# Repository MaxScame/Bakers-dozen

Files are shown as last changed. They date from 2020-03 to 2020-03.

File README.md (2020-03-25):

# Baker's dozen👻
#### [This text in russian➡️](https://github.com/MaxScame/Bakers-dozen/blob/master/README_RU.md)

40% ortholinear keyboard

---
### Layout

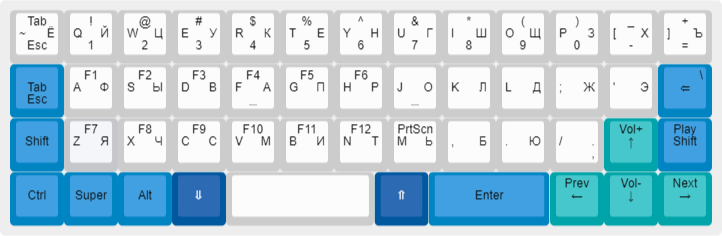
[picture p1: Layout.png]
Keeb-layout Default layout


### PCB

Front:
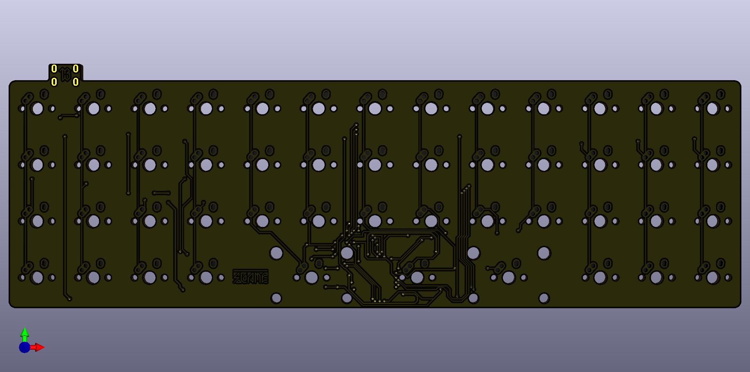
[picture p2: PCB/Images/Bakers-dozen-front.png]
PCB-Front Front side


Back:
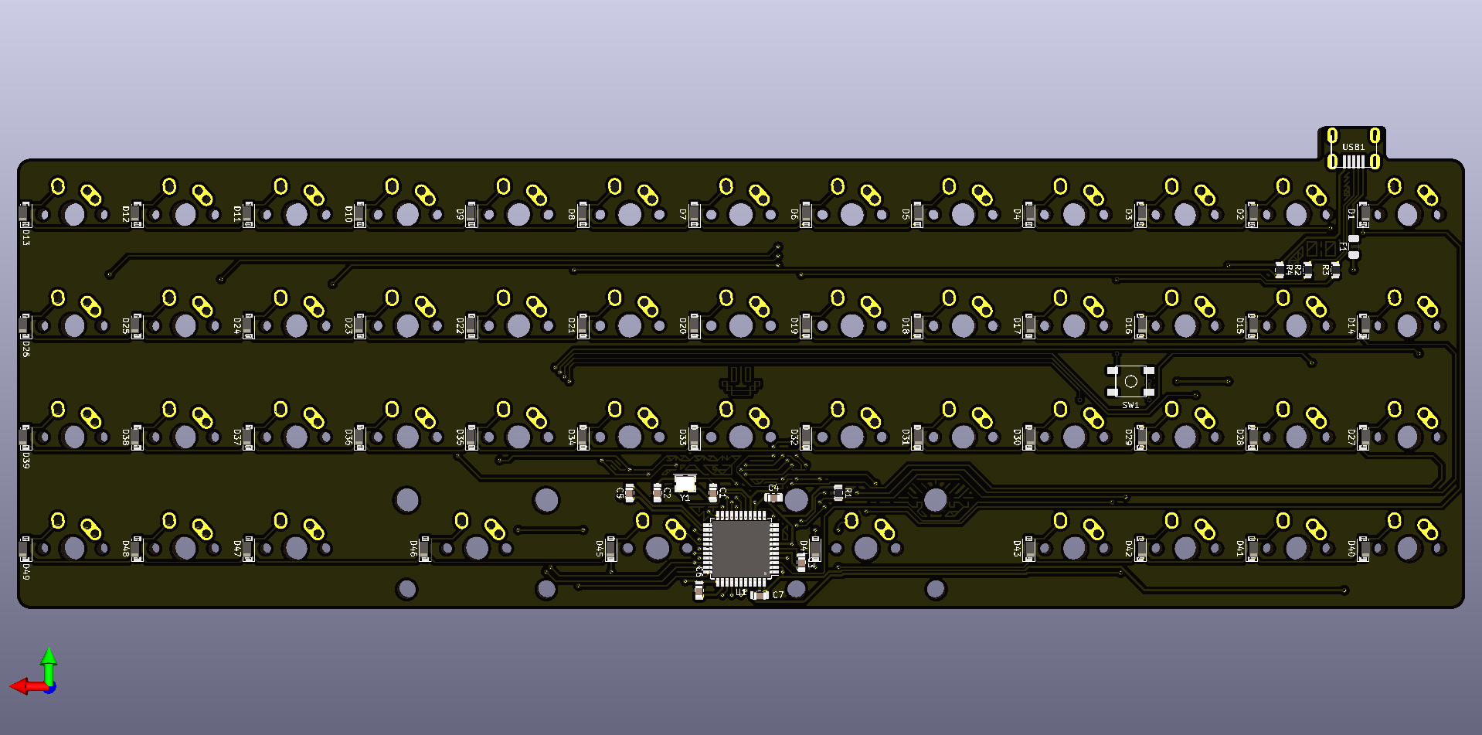
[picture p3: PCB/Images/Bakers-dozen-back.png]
PCB-Back Back side


---
### License
This project is licensed by [MIT](https://github.com/MaxScame/Bakers-dozen/blob/master/LICENSE)

### Credits
ai03-2725 for
- [MX_Alps_Hybrid](https://github.com/ai03-2725/MX_Alps_Hybrid)
- [random-keyboard-parts.pretty](https://github.com/ai03-2725/random-keyboard-parts.pretty)

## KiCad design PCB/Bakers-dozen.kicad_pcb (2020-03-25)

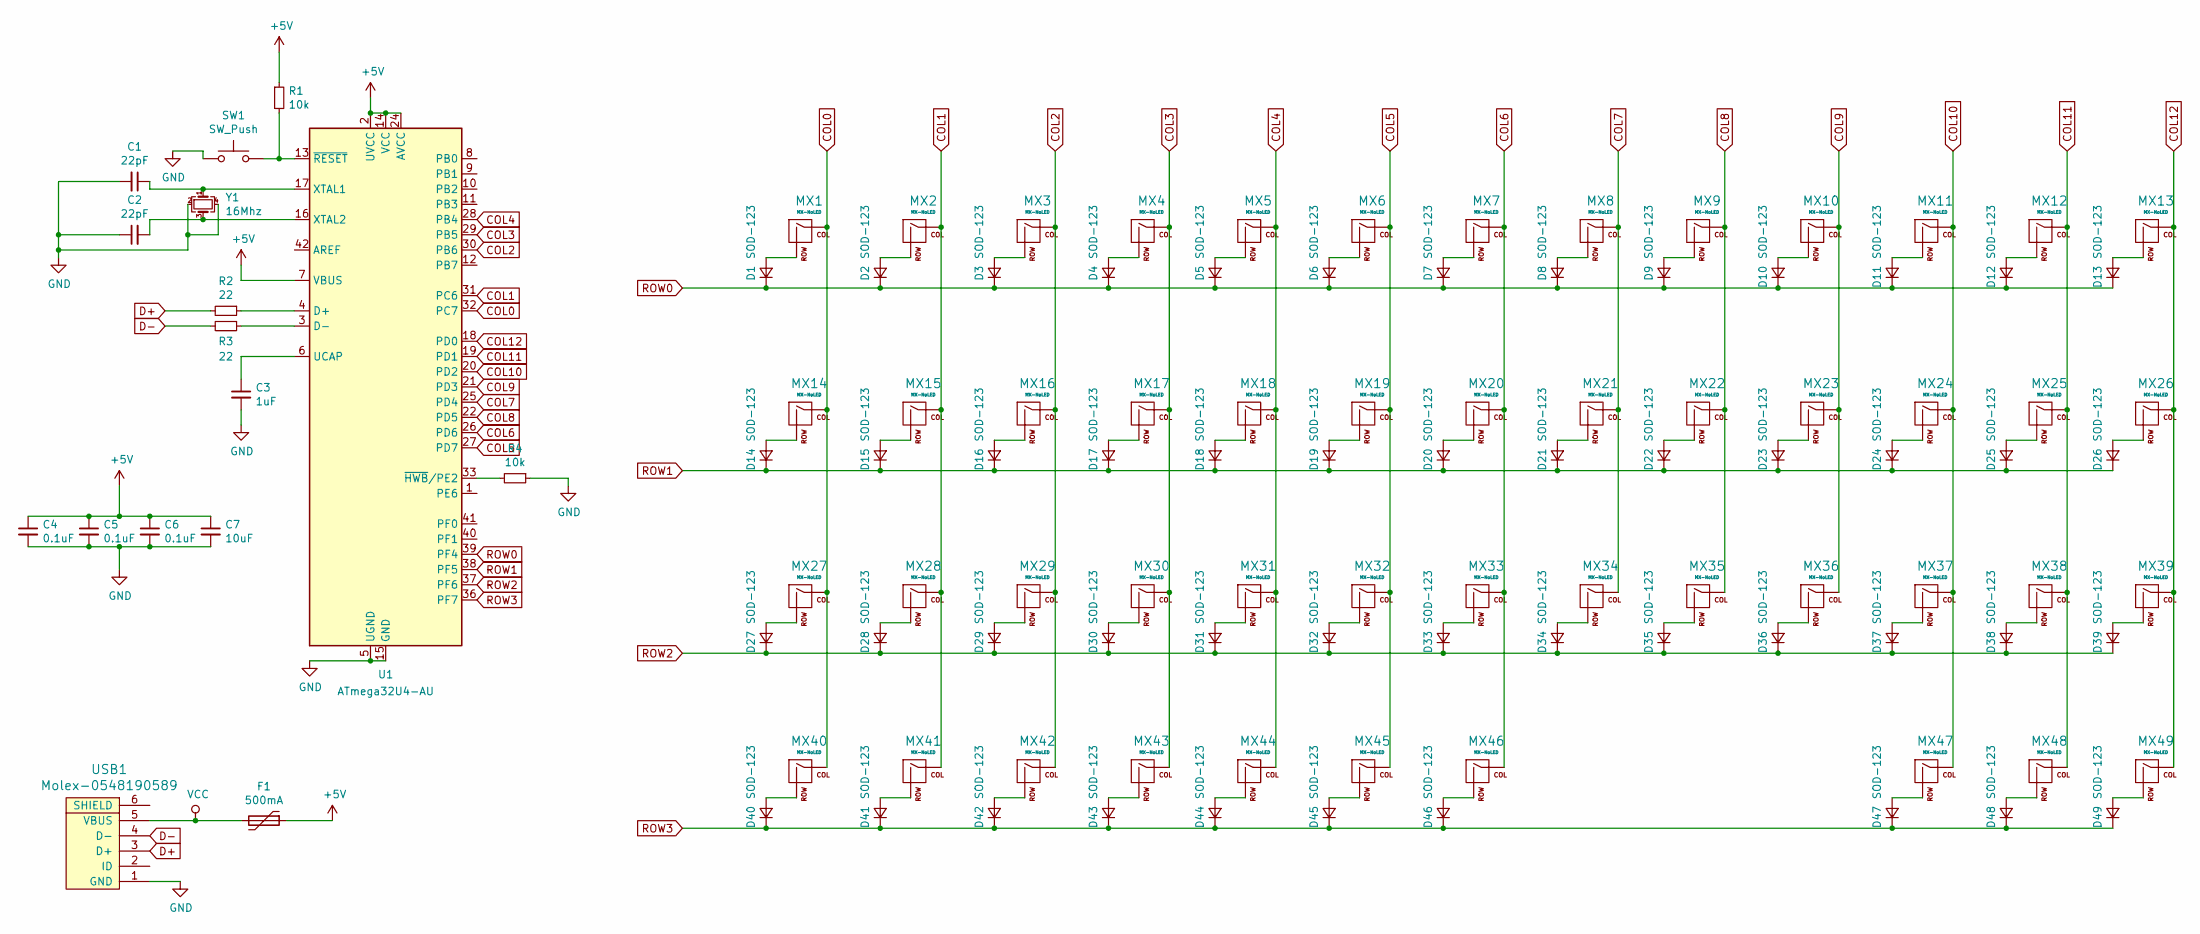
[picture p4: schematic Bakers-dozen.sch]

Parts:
C1, C2: 22pF; C_0805_2012Metric_Pad1.15x1.40mm_HandSolder
C3: 1uF; C_0805_2012Metric_Pad1.15x1.40mm_HandSolder
C4, C5, C6: 0.1uF; C_0805_2012Metric_Pad1.15x1.40mm_HandSolder
C7: 10uF; C_0805_2012Metric_Pad1.15x1.40mm_HandSolder
D1, D2, D3, D4, D5, D6, D7, D8, D9, D10, D11, D12, D13, D14, D15, D16, D17, D18, D19, D20, D21, D22, D23, D24, D25, D26, D27, D28, D29, D30, D31, D32, D33, D34, D35, D36, D37, D38, D39, D40, D41, D42, D43, D44, D45, D46, D47, D48, D49: SOD-123; D_SOD-123
F1: 500mA; Fuse_1206_3216Metric
MX1, MX2, MX3, MX4, MX5, MX6, MX7, MX8, MX9, MX10, MX11, MX12, MX13, MX14, MX15, MX16, MX17, MX18, MX19, MX20, MX21, MX22, MX23, MX24, MX25, MX26, MX27, MX28, MX29, MX30, MX31, MX32, MX33, MX34, MX35, MX36, MX37, MX38, MX39, MX40, MX41, MX42, MX43, MX45, MX47, MX48, MX49: MX-NoLED; MX-1U-NoLED
MX44: MX-NoLED; MX-2.75U-ReversedStabilizers-NoLED
MX46: MX-NoLED; MX-2.25U-ReversedStabilizers-NoLED
R1, R4: 10k; R_0805_2012Metric
R2, R3: 22; R_0805_2012Metric
SW1: SW_Push; SKQG-1155865
U1: ATmega32U4-AU; TQFP-44_10x10mm_P0.8mm
USB1: Molex-0548190589
Y1: 16Mhz; Crystal_SMD_3225-4Pin_3.2x2.5mm

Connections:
+5V: C4.1, C5.1, C6.1, C7.1, F1.1, R1.1, U1.2 (UVCC), U1.7 (VBUS), U1.14 (VCC), U1.24 (AVCC), U1.34 (VCC), U1.44 (AVCC)
COL0: MX1.1 (COL), MX14.1 (COL), MX27.1 (COL), MX40.1 (COL), U1.32 (PC7)
COL1: MX2.1 (COL), MX15.1 (COL), MX28.1 (COL), MX41.1 (COL), U1.31 (PC6)
COL2: MX3.1 (COL), MX16.1 (COL), MX29.1 (COL), MX42.1 (COL), U1.30 (PB6)
COL3: MX4.1 (COL), MX17.1 (COL), MX30.1 (COL), MX43.1 (COL), U1.29 (PB5)
COL4: MX5.1 (COL), MX18.1 (COL), MX31.1 (COL), MX44.1 (COL), U1.28 (PB4)
COL5: MX6.1 (COL), MX19.1 (COL), MX32.1 (COL), MX45.1 (COL), U1.27 (PD7)
COL6: MX7.1 (COL), MX20.1 (COL), MX33.1 (COL), MX46.1 (COL), U1.26 (PD6)
COL7: MX8.1 (COL), MX21.1 (COL), MX34.1 (COL), U1.25 (PD4)
COL8: MX9.1 (COL), MX22.1 (COL), MX35.1 (COL), U1.22 (PD5)
COL9: MX10.1 (COL), MX23.1 (COL), MX36.1 (COL), U1.21 (PD3)
COL10: MX11.1 (COL), MX24.1 (COL), MX37.1 (COL), MX47.1 (COL), U1.20 (PD2)
COL11: MX12.1 (COL), MX25.1 (COL), MX38.1 (COL), MX48.1 (COL), U1.19 (PD1)
COL12: MX13.1 (COL), MX26.1 (COL), MX39.1 (COL), MX49.1 (COL), U1.18 (PD0)
D+: R2.2, USB1.3 (D+)
D-: R3.2, USB1.4 (D-)
GND: C1.2, C2.1, C3.2, C4.2, C5.2, C6.2, C7.2, R4.1, SW1.1, U1.5 (UGND), U1.15 (GND), U1.23 (GND), U1.35 (GND), U1.43 (GND), USB1.1 (GND), Y1.2, Y1.4
unnamed: C1.1, U1.17 (XTAL1), Y1.1
unnamed: C2.2, U1.16 (XTAL2), Y1.3
unnamed: C3.1, U1.6 (UCAP)
unnamed: D1.2 (A), MX1.2 (ROW)
unnamed: D2.2 (A), MX2.2 (ROW)
unnamed: D3.2 (A), MX3.2 (ROW)
unnamed: D4.2 (A), MX4.2 (ROW)
unnamed: D5.2 (A), MX5.2 (ROW)
unnamed: D6.2 (A), MX6.2 (ROW)
unnamed: D7.2 (A), MX7.2 (ROW)
unnamed: D8.2 (A), MX8.2 (ROW)
unnamed: D9.2 (A), MX9.2 (ROW)
unnamed: D10.2 (A), MX10.2 (ROW)
unnamed: D11.2 (A), MX11.2 (ROW)
unnamed: D12.2 (A), MX12.2 (ROW)
unnamed: D13.2 (A), MX13.2 (ROW)
unnamed: D14.2 (A), MX14.2 (ROW)
unnamed: D15.2 (A), MX15.2 (ROW)
unnamed: D16.2 (A), MX16.2 (ROW)
unnamed: D17.2 (A), MX17.2 (ROW)
unnamed: D18.2 (A), MX18.2 (ROW)
unnamed: D19.2 (A), MX19.2 (ROW)
unnamed: D20.2 (A), MX20.2 (ROW)
unnamed: D21.2 (A), MX21.2 (ROW)
unnamed: D22.2 (A), MX22.2 (ROW)
unnamed: D23.2 (A), MX23.2 (ROW)
unnamed: D24.2 (A), MX24.2 (ROW)
unnamed: D25.2 (A), MX25.2 (ROW)
unnamed: D26.2 (A), MX26.2 (ROW)
unnamed: D27.2 (A), MX27.2 (ROW)
unnamed: D28.2 (A), MX28.2 (ROW)
unnamed: D29.2 (A), MX29.2 (ROW)
unnamed: D30.2 (A), MX30.2 (ROW)
unnamed: D31.2 (A), MX31.2 (ROW)
unnamed: D32.2 (A), MX32.2 (ROW)
unnamed: D33.2 (A), MX33.2 (ROW)
unnamed: D34.2 (A), MX34.2 (ROW)
unnamed: D35.2 (A), MX35.2 (ROW)
unnamed: D36.2 (A), MX36.2 (ROW)
unnamed: D37.2 (A), MX37.2 (ROW)
unnamed: D38.2 (A), MX38.2 (ROW)
unnamed: D39.2 (A), MX39.2 (ROW)
unnamed: D40.2 (A), MX40.2 (ROW)
unnamed: D41.2 (A), MX41.2 (ROW)
unnamed: D42.2 (A), MX42.2 (ROW)
unnamed: D43.2 (A), MX43.2 (ROW)
unnamed: D44.2 (A), MX44.2 (ROW)
unnamed: D45.2 (A), MX45.2 (ROW)
unnamed: D46.2 (A), MX46.2 (ROW)
unnamed: D47.2 (A), MX47.2 (ROW)
unnamed: D48.2 (A), MX48.2 (ROW)
unnamed: D49.2 (A), MX49.2 (ROW)
unnamed: R1.2, SW1.2, U1.13 (~RESET)
unnamed: R2.1, U1.4 (D+)
unnamed: R3.1, U1.3 (D-)
unnamed: R4.2, U1.33 (~HWB~/PE2)
ROW0: D1.1 (K), D2.1 (K), D3.1 (K), D4.1 (K), D5.1 (K), D6.1 (K), D7.1 (K), D8.1 (K), D9.1 (K), D10.1 (K), D11.1 (K), D12.1 (K), D13.1 (K), U1.39 (PF4)
ROW1: D14.1 (K), D15.1 (K), D16.1 (K), D17.1 (K), D18.1 (K), D19.1 (K), D20.1 (K), D21.1 (K), D22.1 (K), D23.1 (K), D24.1 (K), D25.1 (K), D26.1 (K), U1.38 (PF5)
ROW2: D27.1 (K), D28.1 (K), D29.1 (K), D30.1 (K), D31.1 (K), D32.1 (K), D33.1 (K), D34.1 (K), D35.1 (K), D36.1 (K), D37.1 (K), D38.1 (K), D39.1 (K), U1.37 (PF6)
ROW3: D40.1 (K), D41.1 (K), D42.1 (K), D43.1 (K), D44.1 (K), D45.1 (K), D46.1 (K), D47.1 (K), D48.1 (K), D49.1 (K), U1.36 (PF7)
VCC: F1.2, USB1.5 (VBUS)

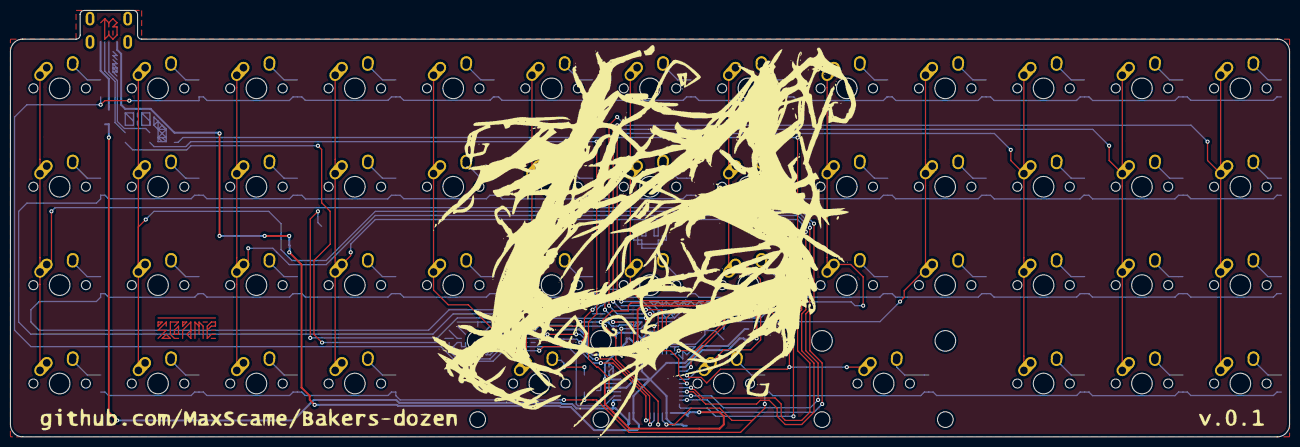
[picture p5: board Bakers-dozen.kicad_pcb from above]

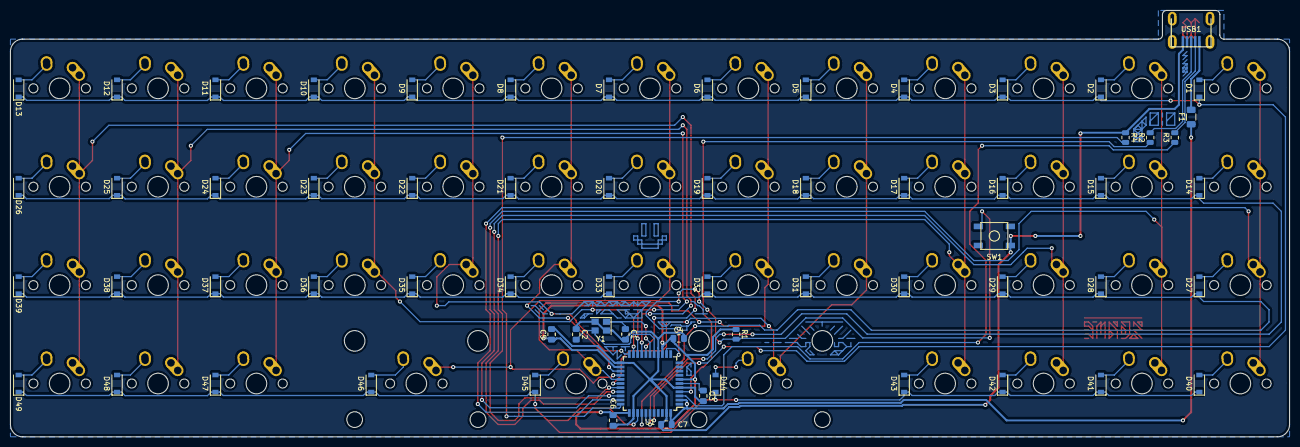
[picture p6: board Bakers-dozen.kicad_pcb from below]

Board: 2 copper layers, 247.7 x 82.5 mm, 114 parts (65 on the bottom side), 78 nets.

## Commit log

2020-03-21 Init KiCad Project
    Now, PCB!
    [Bakers-dozen.kicad_pcb, Bakers-dozen.sch]
2020-03-21 Add footprint libraries
2020-03-22 Finally create schematic
    [Bakers-dozen.sch]
2020-03-23 Plate size and change footprint
    [Bakers-dozen.kicad_pcb, Bakers-dozen.sch]
2020-03-23 Trace pcb
    [Bakers-dozen.kicad_pcb, Bakers-dozen.sch]
2020-03-23 Ground fills
    [Bakers-dozen.kicad_pcb]
2020-03-24 Add some cosmetic changes
    [Bakers-dozen.kicad_pcb]
2020-03-25 Flip stabs
    [Bakers-dozen.kicad_pcb, Bakers-dozen.sch]
2020-03-25 Add gerber files
    [Bakers-dozen-B_Cu.gbr, Bakers-dozen-B_Mask.gbr, Bakers-dozen-B_Paste.gbr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]
